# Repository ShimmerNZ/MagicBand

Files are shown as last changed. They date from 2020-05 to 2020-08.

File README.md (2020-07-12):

# MagicBand
Arduino base Magicband Doorbell and RFID reader

Very much a work in progress at this stage as still waiting after nearly 8 weeks for some parts to arrive from China to test/complete.

The idea was to produce a doorbell that looked similar to the Disney MagicBand readers for my house. It will include a 433mhz transmitter which I intend to send a signal to my RFXCOM receiver connected to my home automation server to play some Haunted Mansion music.

Video of it while in build mode.
https://www.youtube.com/watch?v=pBCrjpx0mSs
https://www.youtube.com/watch?v=BiTqXcxttCY

Components
Arduino nano 5v (but will run down to 2.8 so Lipo ok to power via 5v rail
*TPL5110 5v (but runs on lipo)
433mhz Transmitter 3v rail
RFID Reader 3v rail
DFPlayer 3.2-5 (let's take the 5v rail)
Batteries 2 x 18650 in parallel for long life

subsequent to the build video's I've replaced the TPL5110 with an adafruit Power button https://www.adafruit.com/product/1400
This was a straight swap, had a bigger button area and removed the need of a rather sketchy desoldering of one of the TPLl5110 legs (pin 6), isolating from vcc and connecting to ground in order to get it to work in 'One Shot' mode. Similar power consumption in standby of only 0.5uA so long life for battery.This does sit higher so dremeled the plastic to fit else when screwed together it would have been continually pressed. You may want to consider modifying the stl files if using this instead as it's 4mm higher

Pin Out
TPL5110 (5v)
	POWEROFF	6 - Yellow

WS2812b LED (5v)
	DATA		8 - Orange

DFPlayer (5v)
	RX		2 - Yellow
	TX		3 - Orange

433mhz Transmitter (3v)
	RX		4
	TX		7 - Blue
	PPT		5

RFID (3v)
	RST   		9  - Green
	SDA  		10 - Blue
	MOSI 		11 - White
	MISO 		12 - Yellow
	SCK 		13 - Orange

I had problems with the TPL5110 whereby when you pressed the button it would rapidly blink, this was resolved after placing a 22uf cap across the VIN/DRV pins. (Not required if replacing with the adafruit power button mentioned earlier)

usbasp
368old bootloader
ch340 driver for non fdti chip knock off

this one works
https://www.aliexpress.com/item/33020752786.html

this one doesn't
https://www.aliexpress.com/item/32899642573.html

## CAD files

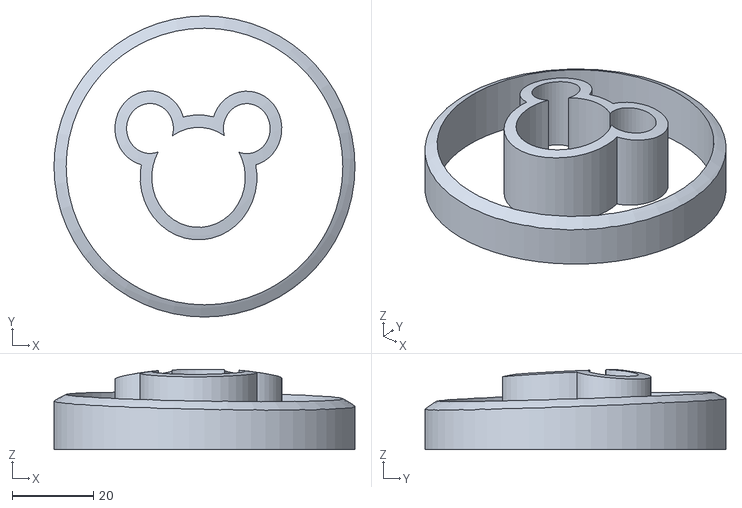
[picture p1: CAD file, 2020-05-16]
transparent - optional.stl
74.0 x 74.0 x 19.7

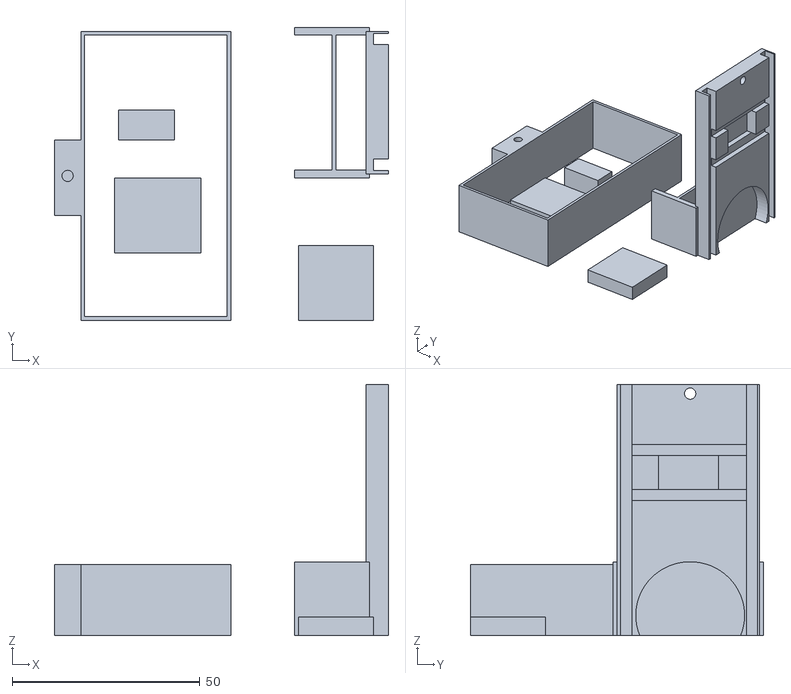
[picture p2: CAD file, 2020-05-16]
version 1 with battery holder.stl
89.0 x 78.0 x 67.0

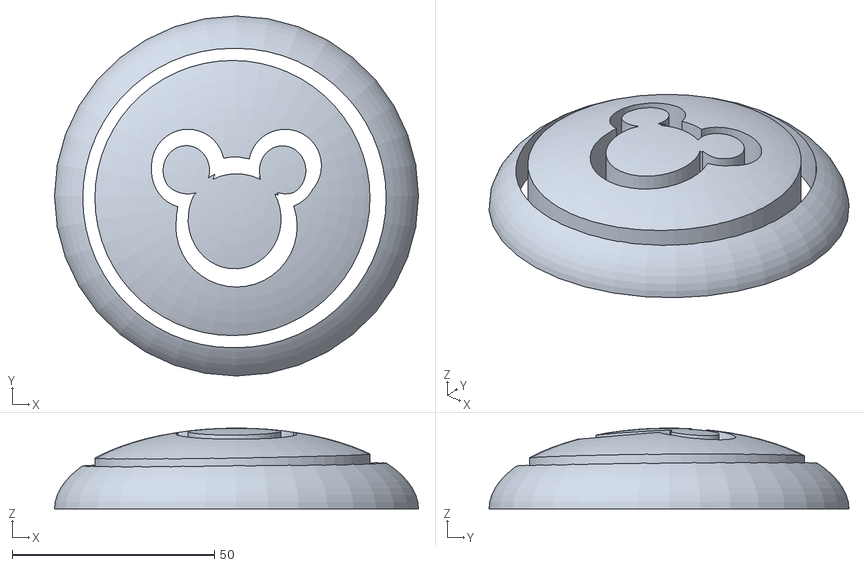
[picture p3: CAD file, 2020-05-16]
Mickey Ring.stl
90.0 x 89.0 x 20.0

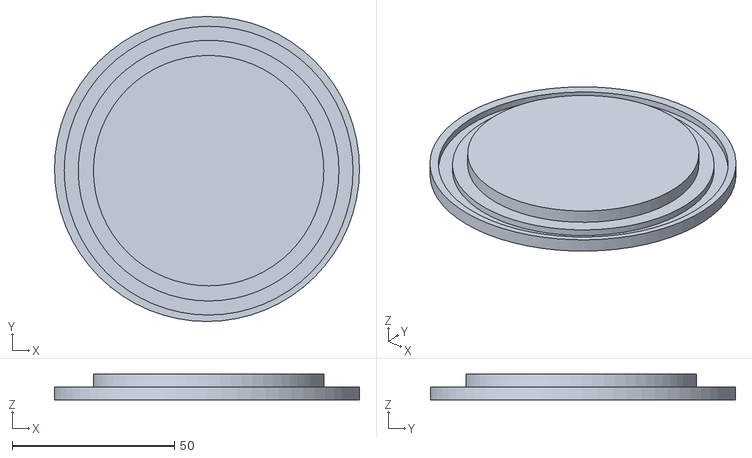
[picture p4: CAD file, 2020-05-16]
plate under ring.stl
94.0 x 94.0 x 8.00

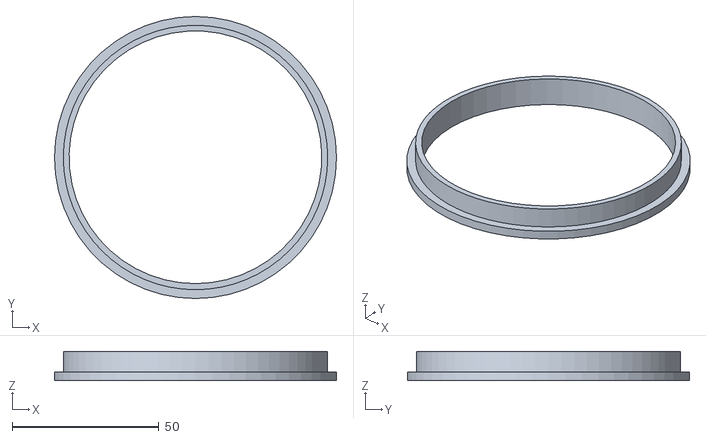
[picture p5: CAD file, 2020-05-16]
Light ring extension.stl
96.0 x 96.0 x 10.0

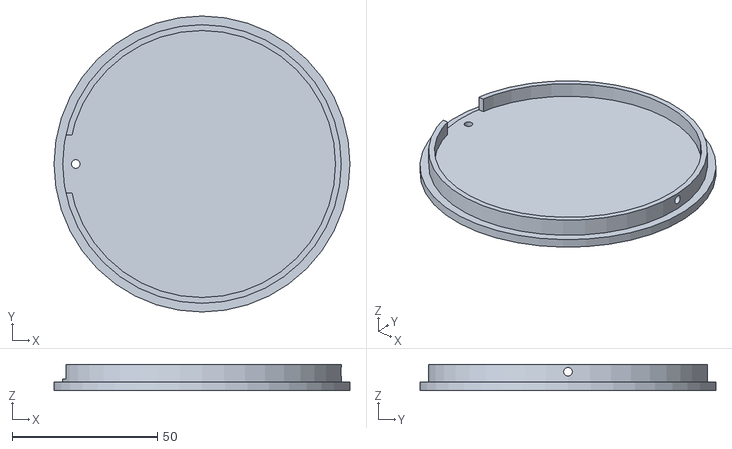
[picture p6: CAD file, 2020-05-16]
Base Plate.stl
102.0 x 102.0 x 9.00

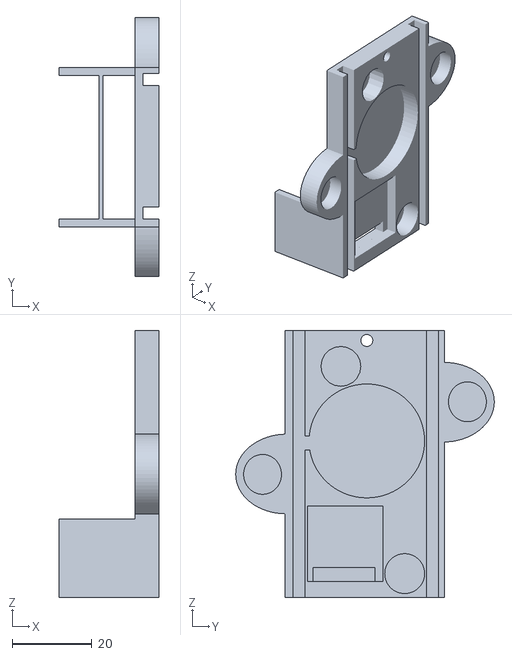
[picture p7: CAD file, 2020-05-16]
Internal Button & Board Support.stl
25.0 x 64.9 x 67.0

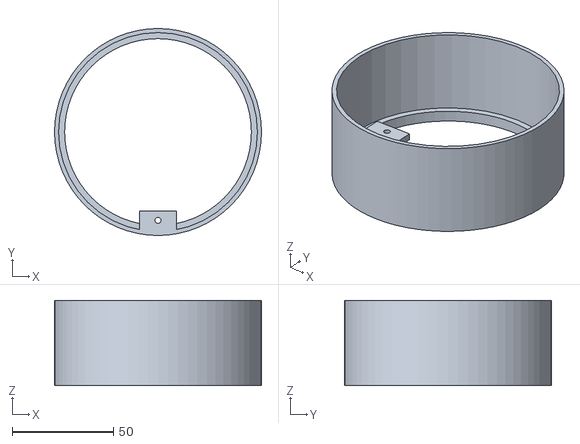
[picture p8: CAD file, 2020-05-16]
Outer Ring.stl
102.0 x 102.0 x 42.0

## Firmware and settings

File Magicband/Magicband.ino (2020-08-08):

//Boards
//Arduino nano 5v (but will run down to 2.8 so Lipo ok to power via 5v rail
//TPL5110 5v (but runs on lipo)
//433mhz Transmitter 3v rail (only receiver is 5v)
//RFID Reader 3v rail
//DFPlayer 3.2-5 (let's take the 5v rail)
//Batteries 2 x 18650 in parallel for long life


#include <Adafruit_NeoPixel.h>
#include "SoftwareSerial.h"
#include "DFRobotDFPlayerMini.h"
#include "MFRC522.h"
#include <SPI.h>

static const uint8_t PIN_MP3_TX = 2; // Connects to DFPlayer module's RX
static const uint8_t PIN_MP3_RX = 3; // Connects to DFPlayer module's TX
#define DONEPIN 6   //Pin to Power Down TPL5110   pin 6
#define RF_DATA_PIN 7 //433mhz Transmitter
#define PIN       8   //LED WS2812b Data Pin
#define RSTPIN   9   //RFID
#define SDAPIN 10 //RFID
#define MOSIPIN 11 //RFID
#define MISOPIN 12 //RFID
#define SCKPIN 13 //RFID
bool RFIDON = false; // set the rfid to false for oneshot button to work
const unsigned int X10_A1_ON = 0x00;            
const unsigned int X10_A1_OFF = 0x20;
const unsigned int X10_address = 5;       // this is Housecode. In my case 5 results in "D" house code
unsigned int X10_data = X10_A1_ON;         // command. I have implemented only On/Off for unit code 1
long randNumber;
MFRC522 mfrc522(SDAPIN, RSTPIN);   // Create MFRC522 instance


#define N_LEDS 57   //Number of WS2812 LED's


SoftwareSerial softwareSerial(PIN_MP3_RX, PIN_MP3_TX);
DFRobotDFPlayerMini player;

//Pixels
Adafruit_NeoPixel strip = Adafruit_NeoPixel(N_LEDS, PIN, NEO_GRB + NEO_KHZ800);
 
void setup() {
   pinMode(DONEPIN, OUTPUT);
   digitalWrite(DONEPIN, LOW);
   softwareSerial.begin(9600);
   randomSeed(analogRead(0));
   pinMode(RF_DATA_PIN, OUTPUT);
   digitalWrite(RF_DATA_PIN   , LOW);
   strip.begin();
   strip.show();
   Serial.begin(9600);      // Initialize serial communications with the PC
   while (!Serial);      // Do nothing if no serial port is opened (added for Arduinos based on ATMEGA32U4)
   SPI.begin();         // Init SPI bus
   Serial.println(F("Init"));
   mfrc522.PCD_Init();    // Init MFRC522
   delay(4);          // Optional delay. Some board do need more time after init to be ready, see Readme
   mfrc522.PCD_DumpVersionToSerial();   // Show details of PCD - MFRC522 Card Reader details
   Serial.println(F("Scan PICC to see UID, SAK, type, and data blocks..."));
 // mfrc522.PCD_SetAntennaGain(mfrc522.RxGain_max);
}
 
void loop() {
   strip.clear();
   if (RFIDON == true) {
          if ( ! mfrc522.PICC_IsNewCardPresent()) {
          return;
          }
          if ( ! mfrc522.PICC_ReadCardSerial()) {
          return;
          }
          String tag = "";
          for (byte i = 0; i < mfrc522.uid.size; i++)
          {
          tag.concat(String(mfrc522.uid.uidByte[i] < 0x10 ? " 0" : " "));
          tag.concat(String(mfrc522.uid.uidByte[i], HEX));
          }
          tag.toUpperCase();
          if (tag.substring(1) == "04 70 35 C2 A1 55 80") //change here the UID of the card/cards that you want to give access
          {
               // If UID of tag is matched.
               Serial.println(F("Magicband 1 read and action started"));
               chase(strip.Color(0, 0, 255));
               if (player.begin(softwareSerial)) {
                     // Set volume to maximum (0 to 30).
                     player.volume(20);
                     // Play the first MP3 file on the SD card
                     player.play(1);
               }
          delay(400);
          brighten();
          darken();
          strip.clear();
          delay(1000);
          digitalWrite(DONEPIN, HIGH);
          delay(10);
          digitalWrite(DONEPIN, LOW);
          }
          if (tag.substring(1) == "04 7B 70 1A 2D 56 80") //change here the UID of the card/cards that you want to give access
          {
            // If UID of tag is matched.
                           Serial.println(F("Magicband 2 read and action started"));
          chase(strip.Color(255,255,255));
               if (player.begin(softwareSerial)) {
                     // Set volume to maximum (0 to 30).
                     player.volume(20);
                     // Play the first MP3 file on the SD card
                     player.play(1);
               }
          delay(400);
          brighten();
          darken();
          strip.clear();
          delay(1000);
          digitalWrite(DONEPIN, HIGH);
          delay(10);
          digitalWrite(DONEPIN, LOW);
          }
   }
   if (RFIDON == false) {
   Serial.println(F("Else Statement"));
      X10_sendState(X10_data);
      Serial.println(F("433mhz Signal Sent"));
   if(X10_data == X10_A1_ON)
      X10_data = X10_A1_OFF;
   else
      X10_data = X10_A1_ON;
   
   randNumber = random(2);
   switch(randNumber)
   {
      case 2:   chase(strip.Color(0, 255, 0)); // Green
                   break;
      case 0:   chase(strip.Color(0, 0, 255)); // Blue
                   break;
      case 1:   chase(strip.Color(255,255,255)); // White
                   break;
   }
   Serial.println(F("Mp3 Start"));
   if (player.begin(softwareSerial)) {
      // Set volume to maximum (0 to 30).
      player.volume(20);
      // Play the first MP3 file on the SD card
      player.play(1);
   }
   delay(400);
   brighten();
   darken();
   strip.clear();
   Serial.println("LED OFF");
   delay(1000);
   digitalWrite(DONEPIN, HIGH);
   Serial.println("PIN DONE");
   delay(10);
   digitalWrite(DONEPIN, LOW);
   RFIDON = true;
} 

// new stuff here

}
 
static void chase(uint32_t c) {
   uint16_t m, n=20;
   for (m=0;   m<15 ; m++) {
      for(uint16_t i=0; i<strip.numPixels()-20; i++) {
            strip.setPixelColor(i   , c); // Draw new pixel
            strip.setPixelColor(i-4, 0); // Erase pixel a few steps back
            if (i<4) {
               strip.setPixelColor(i+33, 0);
            }
            strip.show();
            delay(n);
      }
   n=n*7/8;   
   }
   for(uint16_t i=31; i<strip.numPixels()-20; i++) {
      strip.setPixelColor(i, 0); // Erase pixel a few steps back
      strip.show();
      delay(n);
   }
   strip.clear();
}

void brighten() {
   uint16_t i, j;
   for (j = 0; j < 255; j++) {
      for (i = 0; i < strip.numPixels(); i++) {
         strip.setPixelColor(i, 0, j, 0);
      }
      strip.show();
      delay(2);
   }
}

void darken() {
   uint16_t i, j, q=0, r=0;
   for (j = 255; j > 0; j=j*13/14) {
      for (i = 0; i < strip.numPixels(); i++) {
         if (j>30){ 
            if (i!= r) {
            strip.setPixelColor(i, 0, j, 0);
            }
         }
         else {
            strip.setPixelColor(i, 0, j, 0);   
         }
      }
      strip.show();
      delay(30);
   // put in the twinkle here
      q=q+1;
      if (q=300) { 
         r = random(46);
         strip.setPixelColor(r, 255,255,255);
         strip.show();
         q=0;
      }
   }

    strip.clear();
    strip.show();
}





// new code here

void X10_sendBit_zero()
{
   digitalWrite(RF_DATA_PIN   , HIGH);
   delayMicroseconds(555);          // Arbitrary value: I took around 1.125ms divided by two for the "VCC" state.
   digitalWrite(RF_DATA_PIN   , LOW);
   delayMicroseconds(570);          // Total 555+570 : 1125µs = 1.125ms
}
 
 
void X10_sendBit_one()
{
   digitalWrite(RF_DATA_PIN   , HIGH);
   delayMicroseconds(555);          // Arbitrary value: I took around 1.125ms divided by two for the "VCC" state.
   digitalWrite(RF_DATA_PIN   , LOW);
   delayMicroseconds(1695);         // Total 555+1695 : 2250µs = 2.250ms
}
 
 
 
void X10_send8bits(unsigned int data)
{
   // - Send the 8 bits, and then the complementary of the 8 bits.
   // from documentation: "Within each byte, bit7 is received first and bit0 last"
   int mask = 0x80;
   for(int i = 0; i < 8; i++)
   {
      int bit = mask & data;
      if (bit == 0)
         X10_sendBit_zero();       
      else
         X10_sendBit_one();
 
      mask = mask >> 1;
   }
}
 
void X10_sendByte(unsigned int data)
{
   X10_send8bits(data);
   X10_send8bits(~data);
}
 
 
void X10_sendState_once(unsigned int data)
{
   digitalWrite(RF_DATA_PIN   , HIGH); 
   delayMicroseconds(9000);
   digitalWrite(RF_DATA_PIN   , LOW); 
   delayMicroseconds(4500);

   X10_sendByte(0x50); // - Address
   X10_sendByte(data); // - Data

   digitalWrite(RF_DATA_PIN   , HIGH);
   delayMicroseconds(555);
   digitalWrite(RF_DATA_PIN   , LOW); 
   delayMicroseconds(40000);
}

void X10_sendState(unsigned int data)
{
   digitalWrite(RF_DATA_PIN   , LOW);
   delay(1);   

   // Send 5 times
   for(int repeat=0 ; repeat<5 ; repeat++)
    X10_sendState_once(data);
}

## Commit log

2020-05-16 added 3d print files
    [Base Plate.stl, Internal Button & Board Support.stl, Light ring extension.stl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]
2020-05-16 all components now added. readme updated with pin out and voltage data
2020-05-28 updated led count and logic, changed 433 transmittion from radiohead library to sending x10 code. All now functional.
